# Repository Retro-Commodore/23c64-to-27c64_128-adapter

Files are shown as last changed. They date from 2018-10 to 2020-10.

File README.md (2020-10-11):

# RCEU2305 - 23C64 to 27C64/27C128 ROM to EPROM adapter
A 23C64 ROM to 27C64/27C128 adapter

Meaning you can add a 27C64 or 27C128 eprom to the adapter, and plug the adapter into one of the rom sockets of i.e. the C64, C128 etc.

To use a 27C64, you only need a 28pin socket and 2 x 12pin male/male sil headers, preferably turned/tulip style.

You can make the adapter into a dual rom, by a 27C128 eprom, a 4k7 - 10k ohm resistor, a wire with a 2 way switch connected to the 2 pin header. This will make you able to switch between 2 roms (each 8kB) in the 16kB eprom. 

You can also use this pcb to create an adapter to read the ROM chips in the C64, simply add 2x14pin male/male sil headers in the bottom instead of the 28pin rom socket. and 24pin rom socket on top instead of the 2x12 pin sil headers in the bottom. Basically swap posistions of the socket and the sil haaders.

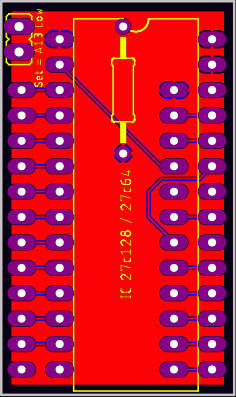
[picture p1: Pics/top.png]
Rom Adapter


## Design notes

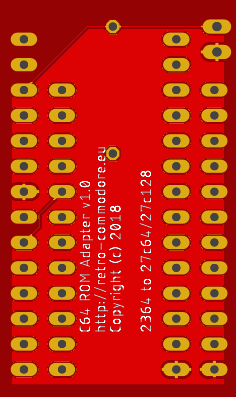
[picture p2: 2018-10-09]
Pics/bottom.png

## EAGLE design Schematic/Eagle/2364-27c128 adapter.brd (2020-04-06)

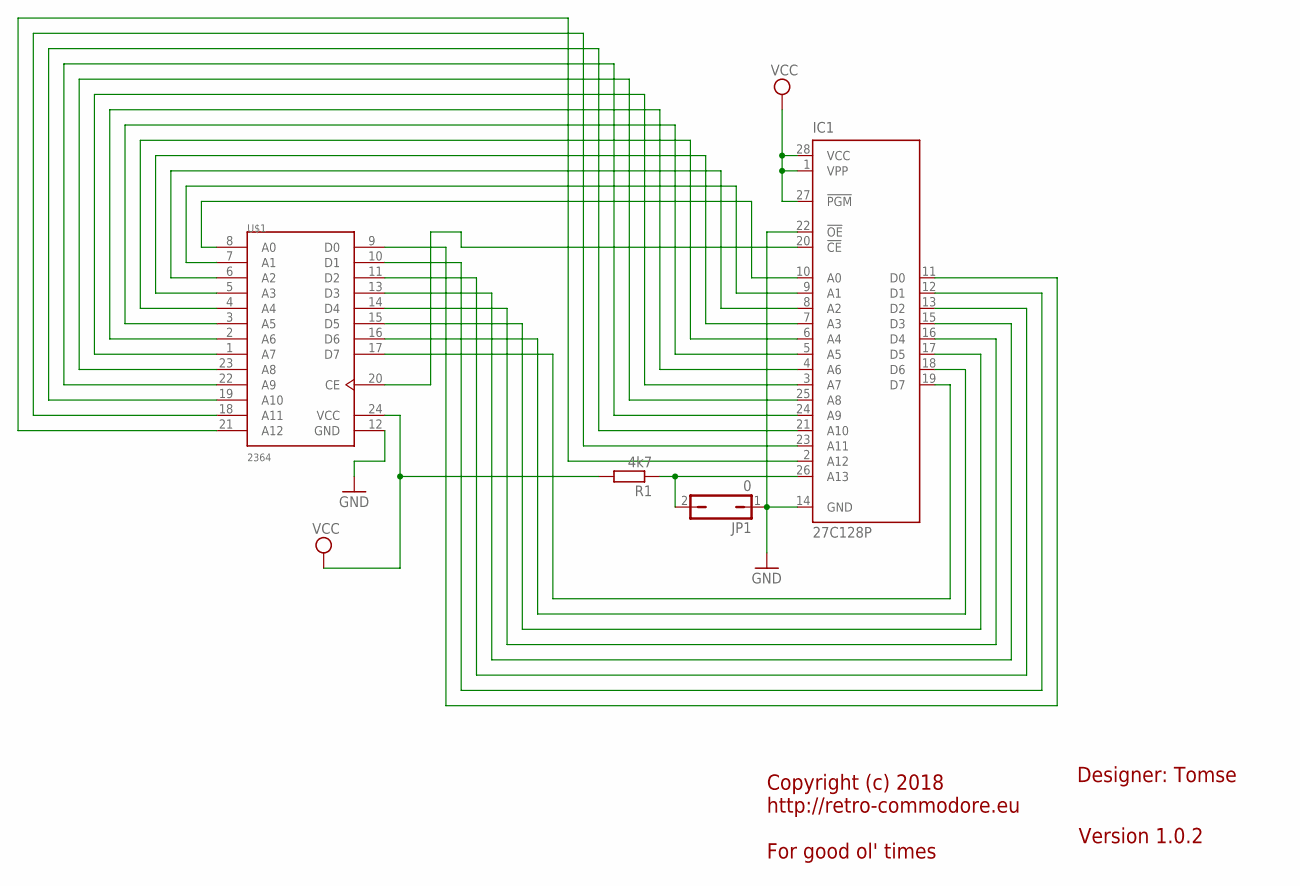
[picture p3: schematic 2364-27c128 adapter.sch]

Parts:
IC1: 27C128P; DIL28-6
JP1: 0; JP1
R1: 4k7; 0207/12
U$1: 2364; DIP24

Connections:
GND: IC1.14 (GND), IC1.22 (!OE), JP1.1, U$1.12 (GND)
unnamed: IC1.10 (A0), U$1.8 (A0)
unnamed: IC1.9 (A1), U$1.7 (A1)
unnamed: IC1.8 (A2), U$1.6 (A2)
unnamed: IC1.7 (A3), U$1.5 (A3)
unnamed: IC1.6 (A4), U$1.4 (A4)
unnamed: IC1.5 (A5), U$1.3 (A5)
unnamed: IC1.4 (A6), U$1.2 (A6)
unnamed: IC1.3 (A7), U$1.1 (A7)
unnamed: IC1.25 (A8), U$1.23 (A8)
unnamed: IC1.24 (A9), U$1.22 (A9)
unnamed: IC1.21 (A10), U$1.19 (A10)
unnamed: IC1.23 (A11), U$1.18 (A11)
unnamed: IC1.2 (A12), U$1.21 (A12)
unnamed: IC1.19 (D7), U$1.17 (D7)
unnamed: IC1.18 (D6), U$1.16 (D6)
unnamed: IC1.17 (D5), U$1.15 (D5)
unnamed: IC1.16 (D4), U$1.14 (D4)
unnamed: IC1.15 (D3), U$1.13 (D3)
unnamed: IC1.13 (D2), U$1.11 (D2)
unnamed: IC1.12 (D1), U$1.10 (D1)
unnamed: IC1.11 (D0), U$1.9 (D0)
unnamed: IC1.20 (!CE), U$1.20 (CE)
unnamed: IC1.26 (A13), JP1.2, R1.1
VCC: IC1.1 (VPP), IC1.27 (!PGM), IC1.28 (VCC), R1.2, U$1.24 (VCC)

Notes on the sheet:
Copyright (c) 2018 http://retro-commodore.eu For good ol' times
Version 1.0.2
Designer: Tomse

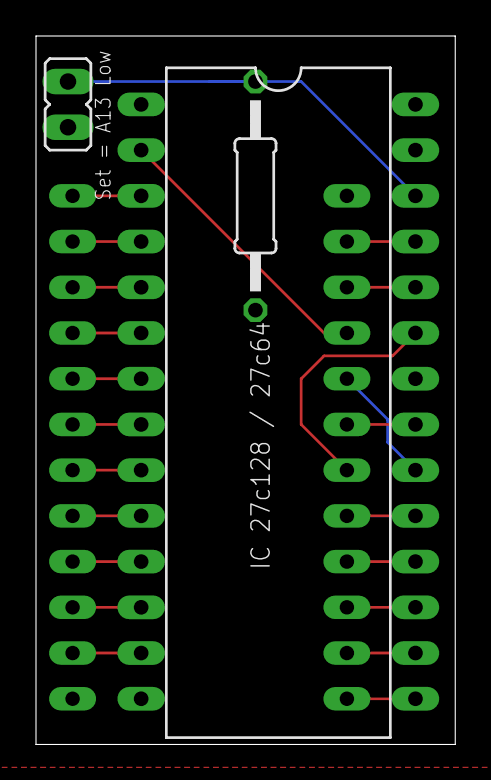
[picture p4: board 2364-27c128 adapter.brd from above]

Board: 2 copper layers, 23.3 x 39.4 mm, 4 parts (0 on the bottom side), 25 nets.

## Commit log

2018-10-09 Update Hardware/Eagle/2364-27c128 adapter.brd
    [2364-27c128 adapter.brd]
2018-10-09 Update Hardware/Eagle/2364-27c128 adapter.sch
    [2364-27c128 adapter.sch]
2020-04-06 Cosmetic changes
    [2364-27c128 adapter.brd, 2364-27c128 adapter.sch]

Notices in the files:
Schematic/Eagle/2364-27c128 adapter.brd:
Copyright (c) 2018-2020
